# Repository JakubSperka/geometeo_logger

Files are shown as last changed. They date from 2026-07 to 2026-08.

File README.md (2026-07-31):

# GeoMeteo Logger

**Prenosný záznamník atmosférických parametrov pre geodetické merania**

> [!NOTE]
> Dokumentácia opisuje aktuálnu vývojovú vetvu **v0.9.0**.  
> Posledný overený stabilný build základnej funkcionality je **v0.9.0**.

GeoMeteo Logger je prenosné zariadenie určené na meranie a záznam:

- teploty vzduchu,
- relatívnej vlhkosti,
- atmosférického tlaku,
- napätia a odhadovaného stavu batérie.

Merania sa ukladajú na SD kartu vo formáte CSV. Zariadenie podporuje automatické aj manuálne záznamy, meracie relácie, živé grafy, obnovu po reštarte, kalibráciu, úsporný režim displeja a bezdrôtový export ukončených relácií cez Wi‑Fi.

> [!NOTE]
> **PLACEHOLDER – FOTO ZARIADENIA**  
> Doplňte fotografiu kompletného zariadenia.  
> Odporúčaný súbor: `docs/images/geometeo-logger-overview.jpg`

---

## Obsah

1. [Hlavné funkcie](#hlavné-funkcie)
2. [Hardvér](#hardvér)
3. [Prvé spustenie](#prvé-spustenie)
4. [Hlavná obrazovka](#hlavná-obrazovka)
5. [Meracie relácie](#meracie-relácie)
6. [Automatické a manuálne záznamy](#automatické-a-manuálne-záznamy)
7. [Grafy](#grafy)
8. [Archív relácií](#archív-relácií)
9. [Kalibrácia](#kalibrácia)
10. [Nastavenia](#nastavenia)
11. [Úspora energie](#úspora-energie)
12. [Wi‑Fi export](#wi-fi-export)
13. [CSV súbory](#csv-súbory)
14. [Odporúčaný postup merania](#odporúčaný-postup-merania)
15. [Stavové a chybové hlásenia](#stavové-a-chybové-hlásenia)
16. [Obnova relácie po reštarte](#obnova-relácie-po-reštarte)
17. [Údržba](#údržba)
18. [Riešenie problémov](#riešenie-problémov)
19. [Štruktúra repozitára](#štruktúra-repozitára)
20. [Licencia](#licencia)

---

## Hlavné funkcie

GeoMeteo Logger poskytuje:

- živé zobrazenie teploty, vlhkosti a tlaku,
- automatický zápis v intervale 1, 5, 10, 30 alebo 60 sekúnd,
- manuálny záznam priradený ku konkrétnemu meranému bodu,
- meraciu reláciu s pevným stanoviskom,
- ukladanie údajov na SD kartu,
- oddelený CSV súbor pre každú reláciu,
- živé grafy posledných 120 záznamov alebo celej relácie,
- archív ukončených relácií,
- obnovenie nedokončenej relácie po reštarte,
- lineárnu kalibráciu každého senzora,
- uloženie surových aj korigovaných hodnôt,
- nastaviteľný jas displeja,
- automatické stlmenie a vypnutie podsvietenia,
- voľbu farebnej schémy používateľského rozhrania,
- export CSV cez vlastnú Wi‑Fi sieť zariadenia,
- validáciu meraných hodnôt a opakovaný pokus o zápis na SD kartu.

---

## Hardvér

### Hlavné komponenty

| Komponent | Použitie |
|---|---|
| LaskaKit ESPD‑35 v3.2 | hlavná doska s ESP32‑S3, TFT displejom a dotykom |
| TFT ILI9488, 480 × 320 px | používateľské rozhranie |
| FT5436/FT6236 | dotyková vrstva |
| SHT40 | teplota a relatívna vlhkosť |
| BMP280 | atmosférický tlak |
| DS3231 | dátum a čas |
| SD karta | ukladanie meracích relácií |
| Li‑Po batéria | prenosné napájanie |

> [!NOTE]
> **PLACEHOLDER – SCHÉMA HARDVÉRU**  
> Doplňte blokovú schému zapojenia zariadenia.  
> Odporúčaný súbor: `docs/images/hardware-block-diagram.png`

### Použité zbernice a piny

#### Interná I²C zbernica

| Signál | GPIO |
|---|---:|
| SDA | 42 |
| SCL | 2 |

Interná zbernica je použitá najmä pre dotykový ovládač. Interné senzory dosky sa vo firmvéri GeoMeteo Logger nepoužívajú.

#### Externá I²C zbernica

| Signál | GPIO |
|---|---:|
| SDA | 5 |
| SCL | 6 |

| Zariadenie | I²C adresa |
|---|---:|
| SHT40 | `0x44` |
| DS3231 | `0x68` |
| BMP280 | `0x77` |

#### SD karta

| Signál | GPIO |
|---|---:|
| SCK | 14 |
| MISO | 21 |
| MOSI | 38 |
| CS | 17 |

#### Batéria

Meranie napätia batérie je pripojené na `GPIO9`.

---

## Prvé spustenie

1. Vložte SD kartu naformátovanú na **FAT32**.
2. Pripojte externý meteorologický modul a RTC.
3. Zapnite zariadenie.
4. Počkajte na dokončenie inicializácie.
5. Skontrolujte stavové indikátory na hlavnej obrazovke.
6. Nastavte správny dátum a čas.
7. Nastavte požadovaný interval automatického záznamu.
8. Pred prvým ostrým meraním vytvorte krátku skúšobnú reláciu.

Po úspešnom štarte sa zobrazí názov projektu a verzia firmvéru:

```text
GEOMETEO LOGGER
vX.Y.Z
```

> [!NOTE]
> **PLACEHOLDER – FOTO ÚVODNEJ OBRAZOVKY**  
> Doplňte fotografiu alebo snímku úvodnej obrazovky.  
> Odporúčaný súbor: `docs/images/startup-screen.jpg`

---

## Hlavná obrazovka

Hlavná obrazovka zobrazuje:

- aktuálny dátum a čas,
- stav batérie,
- teplotu,
- relatívnu vlhkosť,
- atmosférický tlak,
- stanovisko,
- aktuálny meraný bod,
- počet manuálnych záznamov,
- stav senzorov, SD karty, relácie a záznamu,
- tlačidlo na spustenie alebo ukončenie relácie,
- tlačidlo na manuálne uloženie merania,
- skratky do archívu, grafov, Wi‑Fi exportu a nastavení.

> [!NOTE]
> **PLACEHOLDER – HLAVNÁ OBRAZOVKA**  
> Doplňte snímku hlavnej obrazovky s popisom jednotlivých prvkov.  
> Odporúčaný súbor: `docs/images/main-screen-annotated.png`

### Stavové indikátory

Farba bodu vyjadruje stav:

| Farba | Význam |
|---|---|
| zelená | funkcia je pripravená alebo zápis prebehol správne |
| oranžová | upozornenie alebo prechodný stav |
| červená | chyba alebo nedostupná funkcia |
| sivá | funkcia nie je aktívna |

Sledované stavy:

- `SENZOR`
- `SD`
- `RELACIA`
- `ZAZNAM`

---

## Meracie relácie

Každé meranie sa organizuje do samostatnej relácie.

Relácia obsahuje:

- identifikátor relácie,
- stanovisko,
- čas začiatku a konca,
- automatické záznamy,
- manuálne záznamy,
- merané body,
- kalibračné nastavenia použité pri meraní.

### Spustenie relácie

1. Stlačte **SPUSTIT RELACIU**.
2. Zadajte názov alebo číslo stanoviska.
3. Potvrďte zadanie.
4. Zariadenie vytvorí nový CSV súbor.
5. Automatický záznam začne podľa nastaveného intervalu.

Stanovisko je počas relácie uzamknuté.

### Ukončenie relácie

1. Stlačte **UKONCIT RELACIU**.
2. Potvrďte ukončenie.
3. Do CSV sa uloží systémový záznam `SESSION_END`.
4. Súbor zostane dostupný v archíve a cez Wi‑Fi export.

> [!WARNING]
> Pred vypnutím zariadenia odporúčame reláciu vždy korektne ukončiť. Pri neočakávanom vypnutí je však možné reláciu obnoviť.

---

## Automatické a manuálne záznamy

### Automatický záznam

Automatické záznamy sa ukladajú počas aktívnej relácie v nastavenom intervale.

Dostupné intervaly:

- 1 sekunda,
- 5 sekúnd,
- 10 sekúnd,
- 30 sekúnd,
- 60 sekúnd.

Automatický záznam má typ:

```text
AUTO
```

Meraný bod zostáva pri automatickom zázname prázdny.

### Manuálny záznam

Manuálny záznam sa používa na priradenie atmosférických podmienok ku konkrétnemu cieľovému bodu.

Postup:

1. Spustite reláciu.
2. Zadajte meraný bod.
3. Stlačte **ULOZIT MERANIE**.
4. Po úspešnom zápise sa zvýši počítadlo `MANUAL`.
5. Pole meraného bodu sa vymaže a je pripravené na ďalšie zadanie.

Manuálny záznam má typ:

```text
MANUAL
```

Maximálna dĺžka identifikátora stanoviska alebo bodu je 16 znakov.

Podporované sú:

- písmená `A–Z`,
- číslice `0–9`,
- `_`
- `.`
- `,`
- `-`

---

## Grafy

Grafické menu je dostupné počas aktívnej relácie aj z archívu ukončených relácií.

Zobrazované veličiny:

- teplota,
- relatívna vlhkosť,
- atmosférický tlak.

### Rozsah grafu

#### Posledných 120 záznamov

Voľba `120` zobrazí posledných 120 automatických záznamov.

Približný časový rozsah:

| Interval zápisu | Rozsah 120 záznamov |
|---:|---:|
| 1 s | 2 minúty |
| 5 s | 10 minút |
| 10 s | 20 minút |
| 30 s | 1 hodina |
| 60 s | 2 hodiny |

#### Všetky záznamy

Voľba `VSETKY` spracuje celú reláciu. Na displeji sa zobrazí najviac 240 grafických bodov. Pri väčšom počte záznamov sa údaje agregujú, ale minimum, maximum a priemer sa počítajú zo všetkých dostupných záznamov.

### Živé grafy

Počas aktívnej relácie sa graf posledných 120 záznamov aktualizuje po každom úspešnom automatickom zápise.

> [!NOTE]
> **PLACEHOLDER – OBRAZOVKA GRAFOV**  
> Doplňte snímku grafu teploty, vlhkosti a tlaku.  
> Odporúčaný súbor: `docs/images/graphs-screen.png`

---

## Archív relácií

Archív zobrazuje korektne ukončené relácie uložené na SD karte.

Relácie sú:

- zoradené od najnovšej,
- stránkované,
- označené stanoviskom, dátumom, časom a veľkosťou súboru.

Detail relácie obsahuje:

- stanovisko,
- začiatok a koniec,
- trvanie,
- počet automatických záznamov,
- počet manuálnych záznamov,
- minimum, maximum a priemer meraných veličín,
- prístup ku grafom relácie.

Do archívu sa zaraďujú relácie ukončené záznamom:

- `SESSION_END`
- `SESSION_END_RECOVERY`
- `SESSION_ABANDONED`

Aktívna alebo nedokončená relácia sa v archíve nezobrazuje.

> [!NOTE]
> **PLACEHOLDER – ARCHÍV RELÁCIÍ**  
> Doplňte snímku zoznamu relácií a detailu jednej relácie.  
> Odporúčané súbory:  
> `docs/images/archive-list.png`  
> `docs/images/archive-detail.png`

---

## Kalibrácia

Kalibrácia slúži na korekciu rozdielu medzi GeoMeteo Loggerom a referenčným meradlom.

Pre každú veličinu sa používa lineárna korekcia:

```text
korigovaná hodnota = a × meraná hodnota + b
```

Kde:

- `a` je mierkový koeficient,
- `b` je offset.

Kalibrovať možno samostatne:

- teplotu,
- relatívnu vlhkosť,
- atmosférický tlak.

### Neutrálne nastavenie

```text
a = 1.000000
b = 0.000
```

Pri neutrálnom nastavení sa meraná hodnota nemení.

### Povolené rozsahy

| Parameter | Minimum | Maximum |
|---|---:|---:|
| mierkový koeficient `a` | 0,5 | 1,5 |
| teplotný offset `b` | −20 °C | +20 °C |
| vlhkostný offset `b` | −50 % | +50 % |
| tlakový offset `b` | −150 hPa | +150 hPa |

### Uloženie kalibrácie

Kalibračné koeficienty sa ukladajú do internej pamäte ESP32 a zostávajú zachované po reštarte alebo vypnutí zariadenia.

Kalibráciu nemožno meniť počas aktívnej relácie.

> [!IMPORTANT]
> Zmena kalibračných koeficientov je používateľská konfigurácia. Nemení číslo verzie firmvéru.

### Odporúčané získanie koeficientov

1. Umiestnite GeoMeteo Logger a referenčné meradlo vedľa seba.
2. Nechajte oba prístroje ustáliť.
3. Vykonajte viacero súčasných odčítaní.
4. Použite údaje na výpočet lineárnej korekcie.
5. Koeficienty zadajte v kalibračnom menu.
6. Vykonajte kontrolné meranie.

> [!NOTE]
> **PLACEHOLDER – KALIBRAČNÉ MENU**  
> Doplňte snímku obrazovky kalibrácie.  
> Odporúčaný súbor: `docs/images/calibration-screen.png`

---

## Nastavenia

V nastaveniach možno upraviť:

- dátum a čas RTC,
- interval automatického záznamu,
- jas displeja,
- kalibráciu,
- úsporu energie,
- farebnú schému používateľského rozhrania.

### Dátum a čas

Dátum a čas sa nastavujú v samostatnom editore. Zmena ostatných nastavení nemení RTC.

### Jas displeja

Jas možno nastaviť v rozsahu približne 10 až 100 %.

### Farebná schéma

Dostupné akcentové farby:

- oranžová,
- modrá,
- zelená,
- červená,
- fialová.

Výber sa uloží do internej pamäte a zostane zachovaný po reštarte.

Farebná schéma ovplyvňuje najmä:

- panely meraných hodnôt,
- aktívne tlačidlá,
- ikony,
- rámčeky,
- posuvník jasu,
- grafické akcenty,
- webovú stránku Wi‑Fi exportu.

Stavové farby upozornení zostávajú nezávislé od zvolenej schémy.

> [!NOTE]
> **PLACEHOLDER – NASTAVENIA A FARBY**  
> Doplňte snímku hlavného nastavenia a výberu farebnej schémy.  
> Odporúčané súbory:  
> `docs/images/settings-screen.png`  
> `docs/images/accent-theme-screen.png`

---

## Úspora energie

Úsporný režim ovplyvňuje iba podsvietenie displeja. Meranie a zápis na SD kartu pokračujú bez prerušenia.

Dostupný čas nečinnosti pred stlmením:

- 30 sekúnd,
- 1 minúta,
- 2 minúty,
- 5 minút.

Po uplynutí nastaveného času:

1. displej sa stlmí približne na 5 %,
2. po ďalších 30 sekundách sa podsvietenie vypne,
3. prvý dotyk displej iba prebudí,
4. až ďalší dotyk vykoná požadovanú akciu.

Predvolené nastavenie:

```text
úspora energie: zapnutá
stlmenie: po 1 minúte
vypnutie: o ďalších 30 sekúnd
```

Počas Wi‑Fi exportu zostáva displej aktívny.

---

## Wi‑Fi export

GeoMeteo Logger umožňuje stiahnuť ukončené CSV relácie bez vyberania SD karty.

Zariadenie vytvorí vlastnú Wi‑Fi sieť. Router ani internet nie sú potrebné.

### Spustenie exportu

1. Ukončite aktívnu meraciu reláciu.
2. Otvorte Wi‑Fi menu.
3. Stlačte **SPUSTIT WI-FI**.
4. V počítači alebo telefóne vyhľadajte sieť:

```text
GeoMeteo-XXXX
```

5. Pripojte sa pomocou hesla:

```text
geometeo
```

6. V prehliadači otvorte:

```text
http://192.168.4.1
```

7. Vyberte reláciu a stlačte **STIAHNUT CSV**.

### Dôležité vlastnosti

- exportujú sa iba ukončené relácie,
- aktívnu reláciu nemožno exportovať,
- Wi‑Fi sa po piatich minútach bez aktivity automaticky vypne,
- odchod z Wi‑Fi menu export ukončí,
- CSV sa prenáša priamo zo SD karty,
- pripojenie nemá prístup na internet.

> [!NOTE]
> Telefón alebo počítač môže oznámiť, že Wi‑Fi sieť nemá internet. Zostaňte k nej pripojení a ručne otvorte adresu `192.168.4.1`.

> [!NOTE]
> **PLACEHOLDER – WI‑FI EXPORT**  
> Doplňte fotografiu Wi‑Fi menu a snímku webovej stránky.  
> Odporúčané súbory:  
> `docs/images/wifi-export-device.png`  
> `docs/images/wifi-export-browser.png`

---

## CSV súbory

Každá relácia sa ukladá do samostatného súboru v priečinku:

```text
/sessions
```

### Stĺpce CSV

| Stĺpec | Význam |
|---|---|
| `session_id` | identifikátor relácie |
| `timestamp` | dátum a čas záznamu |
| `record_type` | typ záznamu |
| `station` | stanovisko |
| `target_point` | meraný bod |
| `temperature_c` | korigovaná teplota |
| `humidity_pct` | korigovaná relatívna vlhkosť |
| `pressure_hpa` | korigovaný atmosférický tlak |
| `battery_voltage_v` | napätie batérie |
| `battery_percent` | odhad stavu batérie |
| `temperature_raw_c` | pôvodná hodnota teploty |
| `humidity_raw_pct` | pôvodná hodnota vlhkosti |
| `pressure_raw_hpa` | pôvodná hodnota tlaku |
| `calibration_enabled` | stav kalibrácie |
| `temperature_scale` | koeficient `a` pre teplotu |
| `temperature_offset_c` | koeficient `b` pre teplotu |
| `humidity_scale` | koeficient `a` pre vlhkosť |
| `humidity_offset_pct` | koeficient `b` pre vlhkosť |
| `pressure_scale` | koeficient `a` pre tlak |
| `pressure_offset_hpa` | koeficient `b` pre tlak |

### Typy záznamov

| Typ | Význam |
|---|---|
| `SESSION_START` | začiatok relácie |
| `AUTO` | automatický merací záznam |
| `MANUAL` | manuálny záznam ku konkrétnemu bodu |
| `SESSION_RESUME` | pokračovanie obnovenej relácie |
| `SESSION_END` | korektné ukončenie relácie |
| `SESSION_END_RECOVERY` | ukončenie obnovenej relácie |
| `SESSION_ABANDONED` | opustenie nedokončenej relácie |

### Ukážka

```csv
session_id,timestamp,record_type,station,target_point,temperature_c,humidity_pct,pressure_hpa,battery_voltage_v,battery_percent,temperature_raw_c,humidity_raw_pct,pressure_raw_hpa,calibration_enabled,temperature_scale,temperature_offset_c,humidity_scale,humidity_offset_pct,pressure_scale,pressure_offset_hpa
20260727_083200,2026-07-27 08:32:00,SESSION_START,ST_01,,,,4.08,87,,,,0,1.000000,0.000,1.000000,0.000,1.000000,0.000
20260727_083200,2026-07-27 08:32:05,AUTO,ST_01,,24.53,46.10,999.35,4.08,87,24.53,46.10,999.35,0,1.000000,0.000,1.000000,0.000,1.000000,0.000
20260727_083200,2026-07-27 08:33:12,MANUAL,ST_01,BOD_101,24.55,46.20,999.34,4.07,86,24.55,46.20,999.34,0,1.000000,0.000,1.000000,0.000,1.000000,0.000
```

> [!NOTE]
> Uvedené hodnoty sú iba ilustračné.

---

## Odporúčaný postup merania

### Pred meraním

1. Skontrolujte nabitie batérie.
2. Skontrolujte vloženie SD karty.
3. Overte dátum a čas.
4. Skontrolujte stav senzorov.
5. Nechajte zariadenie ustáliť v prostredí merania.
6. Až potom spustite reláciu.

### Odporúčaná doba ustálenia

Firmvér neobsahuje povinnú čakaciu dobu. Používateľ môže reláciu spustiť okamžite.

Pre spoľahlivejšie výsledky sa odporúča:

| Situácia | Odporúčaná doba |
|---|---:|
| bežné spustenie | približne 60 sekúnd |
| výrazná zmena prostredia | 5 až 10 minút |
| kalibračné porovnanie | 10 až 15 minút |

### Umiestnenie senzora

Senzor umiestnite:

- mimo priameho slnečného žiarenia,
- mimo tepla ruky používateľa,
- mimo výduchu teplého vzduchu,
- s dostatočným prúdením vzduchu,
- čo najďalej od elektroniky a displeja,
- v ochrannom, ale vetranom kryte.

> [!NOTE]
> **PLACEHOLDER – UMIESTNENIE SENZORA**  
> Doplňte fotografiu odporúčaného umiestnenia externého senzora v kryte.  
> Odporúčaný súbor: `docs/images/sensor-placement.jpg`

---

## Stavové a chybové hlásenia

Zariadenie kontroluje:

- komunikáciu so SHT40,
- komunikáciu s BMP280,
- platnosť RTC,
- dostupnosť SD karty,
- úspešnosť zápisu,
- platnosť meraných rozsahov,
- stav batérie.

Príklady hlásení:

```text
CHYBA CITANIA SHT40
CHYBA CITANIA BMP280
NEPLATNY DATUM ALEBO CAS RTC
TEPLOTA MIMO PLATNEHO ROZSAHU
VLHKOST MIMO PLATNEHO ROZSAHU
TLAK MIMO PLATNEHO ROZSAHU
CHYBA ZAPISU NA SD
BATERIA KRITICKA
```

Neplatné meranie sa neuloží ako `AUTO` ani `MANUAL`.

### Platné rozsahy meraní

| Veličina | Minimum | Maximum |
|---|---:|---:|
| teplota | −40 °C | 85 °C |
| relatívna vlhkosť | 0 % | 100 % |
| tlak | 300 hPa | 1100 hPa |
| rok RTC | 2020 | 2099 |

### Batéria

| Stav | Indikácia |
|---|---|
| viac ako 25 % | zelená |
| 11 až 25 % | oranžová |
| 0 až 10 % | červená |

Pri kritickej úrovni zariadenie odporučí ukončiť reláciu, ale nevypne ju automaticky.

---

## Obnova relácie po reštarte

Po neočakávanom vypnutí alebo reštarte zariadenie rozpozná nedokončenú reláciu.

Používateľ môže zvoliť:

### Pokračovať

- obnoví stanovisko,
- obnoví CSV súbor,
- obnoví počet manuálnych záznamov,
- zapíše `SESSION_RESUME`.

### Ukončiť

- uzavrie pôvodnú reláciu,
- zapíše `SESSION_END_RECOVERY`.

### Nová relácia

- označí pôvodnú reláciu ako `SESSION_ABANDONED`,
- vymaže uložený aktívny stav,
- umožní založiť novú reláciu.

> [!NOTE]
> **PLACEHOLDER – OBNOVA RELÁCIE**  
> Doplňte snímku obrazovky obnovy po reštarte.  
> Odporúčaný súbor: `docs/images/session-recovery.png`

---

## Údržba

### SD karta

- používajte kartu naformátovanú na FAT32,
- kartu nevyberajte počas zápisu,
- pred vybratím ukončite reláciu a vypnite zariadenie,
- pravidelne zálohujte CSV súbory,
- pri opakovaných chybách zápisu kartu preformátujte alebo vymeňte.

### Senzory

- chráňte ich pred kondenzáciou a priamym dažďom,
- nevystavujte ich zbytočne prachu,
- neumiestňujte ich do uzavretého nevetraného priestoru,
- pred kalibráciou zabezpečte rovnaké podmienky pre oba prístroje.

### Batéria

- zariadenie nabíjajte vhodným USB zdrojom,
- nenechávajte batériu dlhodobo úplne vybitú,
- pri dlhšom skladovaní zariadenie pravidelne skontrolujte.

---

## Riešenie problémov

### Zariadenie nevidí SD kartu

1. Vypnite zariadenie.
2. Skontrolujte vloženie karty.
3. Overte formát FAT32.
4. Skúste inú SD kartu.
5. Skontrolujte stav `SD` po opätovnom zapnutí.

### Meranie sa neukladá

Skontrolujte:

- či je aktívna relácia,
- či je zadané stanovisko,
- pri manuálnom zázname aj meraný bod,
- stav SD karty,
- platnosť hodnôt senzorov.

Počítadlo manuálnych záznamov sa zvýši iba po potvrdenom zápise.

### Zobrazované hodnoty sa líšia od referenčného meradla

1. Nechajte oba prístroje ustáliť.
2. Skontrolujte ich umiestnenie.
3. Pri tlaku overte, že oba prístroje zobrazujú rovnaký typ tlaku.
4. Vykonajte viacero porovnávacích meraní.
5. Vypočítajte a nastavte kalibračné koeficienty.

### Wi‑Fi stránka sa neotvorí

1. Overte, že je Wi‑Fi export spustený.
2. Skontrolujte pripojenie k sieti `GeoMeteo-XXXX`.
3. Zostaňte pripojení aj bez internetu.
4. Otvorte priamo `http://192.168.4.1`.
5. Skontrolujte, či sa Wi‑Fi po časovom limite nevypnula.

### CSV súbor sa nedá stiahnuť

- relácia musí byť ukončená,
- SD karta musí byť dostupná,
- Wi‑Fi musí zostať aktívna počas celého prenosu,
- pri veľkom súbore počkajte na dokončenie prenosu.

### Displej nereaguje na prvý dotyk

Pri stlmenom alebo vypnutom displeji je to očakávané správanie. Prvý dotyk iba prebudí podsvietenie. Druhý dotyk vykoná požadovanú akciu.

---

## Štruktúra repozitára

Odporúčaná štruktúra:

```text
GeoMeteo-Logger/
├── README.md
├── LICENSE
├── firmware/
│   ├── geometeo_logger.ino
│   ├── FT6236.h
│   └── FT6236.cpp
├── docs/
│   ├── user-guide.md
│   ├── hardware.md
│   ├── csv-format.md
│   └── images/
│       ├── geometeo-logger-overview.jpg
│       ├── hardware-block-diagram.png
│       ├── main-screen-annotated.png
│       ├── graphs-screen.png
│       ├── archive-list.png
│       ├── archive-detail.png
│       ├── calibration-screen.png
│       ├── settings-screen.png
│       ├── accent-theme-screen.png
│       ├── wifi-export-device.png
│       ├── wifi-export-browser.png
│       ├── sensor-placement.jpg
│       └── session-recovery.png
└── examples/
    └── sample-session.csv
```

---

## Vývojové prostredie

Projekt bol vyvíjaný a testovaný s:

- Arduino IDE 2.3.10,
- balíkom ESP32 3.3.11,
- doskou LaskaKit ESPD‑35 v3.2.

Použité knižnice:

```cpp
#include <Arduino.h>
#include <Wire.h>
#include <SPI.h>
#include <FS.h>
#include <SD.h>
#include <TFT_eSPI.h>
#include "FT6236.h"
#include <Adafruit_SHT4x.h>
#include <Adafruit_BMP280.h>
#include <RTClib.h>
#include <Preferences.h>
#include <WiFi.h>
#include <WebServer.h>
```

Pre TFT_eSPI sa používa konfigurácia displeja určená pre ESPD‑35 v3:

```text
Setup303_ILI9488_ESPD-3_5_v3.h
```

---

## Verzionovanie

Projekt používa verzie vo formáte:

```text
MAJOR.MINOR.PATCH
```

Príklad:

```text
v0.8.0
```

- `MAJOR` – zásadná zmena alebo stabilné verejné vydanie,
- `MINOR` – nová funkcia,
- `PATCH` – oprava alebo menšia úprava.

Zmena používateľských nastavení, napríklad kalibračných koeficientov, jasu, intervalu alebo farebnej schémy, nemení verziu firmvéru.

---

## Licencia

```text
MIT License
```

Výber závisí od požadovaných podmienok ďalšieho používania a úprav.

---

## Autor a kontakt

```text
Autor: Jakub Špekra
Pracovisko: Karedra globálnej geodézie a geoinformatiky, Stavebná Fakulta STU v Bratislava
E-mail: jakub.sperka@stuba.sk
Repozitár: geometeo_logger
```

---

## Stav projektu

GeoMeteo Logger poskytuje kompletný pracovný tok pre terénny záznam atmosférických parametrov:

```text
spustenie
→ kontrola zariadení
→ založenie relácie
→ automatické a manuálne meranie
→ grafická kontrola
→ ukončenie relácie
→ archív
→ export CSV cez Wi‑Fi
→ spracovanie údajov v počítači
```

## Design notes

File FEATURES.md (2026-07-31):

# GeoMeteo Logger – prehľad funkcionalít

Tento dokument sumarizuje funkcionalitu zariadenia **GeoMeteo Logger** implementovanú vo firmvéri do verzie **v0.9.0**.

> [!NOTE]
> Verzia **v0.7.6** bola označená ako stabilný referenčný build.  
> Verzia **v0.9.0** obsahuje všetky neskoršie rozšírenia vrátane farebných schém a ochrany úložiska a je určená na overenie pred označením za nový stable release.

---

## 1. Merané veličiny

Zariadenie meria a zobrazuje:

- teplotu vzduchu zo senzora SHT40,
- relatívnu vlhkosť zo senzora SHT40,
- absolútny atmosférický tlak zo senzora BMP280,
- napätie Li‑Po batérie,
- odhad percentuálneho stavu batérie,
- dátum a čas z RTC DS3231.

Interné meteorologické senzory hlavnej dosky sa nepoužívajú. Firmvér pracuje s externým meteorologickým modulom na samostatnej I²C zbernici.

### Frekvencia čítania senzorov

Atmosférické hodnoty sa interne obnovujú približne každú sekundu bez ohľadu na nastavený interval zápisu do CSV.

### Kontrola platnosti meraní

Pred uložením sa kontrolujú rozsahy:

| Veličina | Minimum | Maximum |
|---|---:|---:|
| teplota | −40 °C | 85 °C |
| relatívna vlhkosť | 0 % | 100 % |
| tlak | 300 hPa | 1100 hPa |
| rok RTC | 2020 | 2099 |

Pri neplatnej hodnote sa automatický ani manuálny merací záznam neuloží. Systémové udalosti relácie sa môžu uložiť aj bez platných atmosferických hodnôt.

---

## 2. Hlavná obrazovka

Hlavná obrazovka v portrétnej orientácii zobrazuje:

- dátum a čas,
- percento a napätie batérie,
- teplotu,
- relatívnu vlhkosť,
- tlak,
- stanovisko,
- aktuálny meraný bod,
- počet manuálnych záznamov vo formáte `MANUAL: n`,
- stavový riadok s aktuálnou informáciou alebo chybou,
- stavové indikátory zariadenia,
- tlačidlo na spustenie alebo ukončenie relácie,
- tlačidlo manuálneho uloženia,
- skratky do archívu, grafov, Wi‑Fi exportu a nastavení.

Merané hodnoty používajú jemne zosilnený čierny font na farebnom pozadí.

### Stavové indikátory

Indikátory používajú celé názvy:

- `SENZOR`
- `SD`
- `RELACIA`
- `ZAZNAM`

Ich farby nepodliehajú používateľskej farebnej téme:

| Farba | Význam |
|---|---|
| zelená | pripravené alebo úspešné |
| oranžová | upozornenie, čakanie alebo neaktívny stav |
| červená | chyba |

---

## 3. Meracie relácie

Každé meranie sa organizuje do samostatnej relácie.

### Spustenie relácie

Jedno kontextové tlačidlo slúži na spustenie aj ukončenie relácie:

```text
SPUSTIT RELACIU
UKONCIT RELACIU
```

Pri spustení používateľ zadá stanovisko. Stanovisko zostáva počas celej relácie nemenné.

### Identifikátory

Stanovisko a meraný bod môžu mať najviac 16 znakov.

Podporované znaky:

- `A–Z`
- `0–9`
- `_`
- `.`
- `,`
- `-`

CSV zápis správne uzatvára textové polia do úvodzoviek, ak obsahujú čiarku alebo úvodzovku.

### Ukončenie relácie

Ukončenie sa vykonáva cez potvrdzovaciu obrazovku. Pri úspešnom ukončení sa zapíše systémová udalosť `SESSION_END`.

---

## 4. Automatický záznam

Počas aktívnej relácie sa údaje automaticky zapisujú do CSV.

Dostupné intervaly:

- 1 sekunda,
- 5 sekúnd,
- 10 sekúnd,
- 30 sekúnd,
- 60 sekúnd.

Predvolený interval je 5 sekúnd.

Automatický záznam má typ:

```text
AUTO
```

Pole meraného bodu zostáva pri automatickom zázname prázdne.

---

## 5. Manuálny záznam

Manuálny záznam umožňuje priradiť aktuálne atmosferické podmienky ku konkrétnemu meranému bodu.

Pracovný postup:

1. spustenie relácie,
2. zadanie meraného bodu,
3. uloženie merania,
4. potvrdenie úspešného zápisu,
5. zvýšenie počítadla `MANUAL`,
6. automatické vymazanie poľa meraného bodu.

Manuálny záznam má typ:

```text
MANUAL
```

Počítadlo sa zvýši iba po potvrdenom zápise na SD kartu.

---

## 6. Softvérová klávesnica

Zariadenie obsahuje dotykovú alfanumerickú klávesnicu.

Podporuje:

- číselný režim,
- abecedný režim,
- prepínanie režimov,
- mazanie posledného znaku,
- vymazanie celého vstupu,
- potvrdenie a zrušenie zadávania,
- samostatný numerický editor kalibračných koeficientov.

---

## 7. Ukladanie na SD kartu

Každá relácia má vlastný CSV súbor v priečinku:

```text
/sessions
```

### Bezpečný zápis

Pri každom zázname firmvér:

1. otvorí súbor v režime append,
2. zapíše celý CSV riadok,
3. vykoná `flush()`,
4. skontroluje chybu zápisu,
5. zatvorí súbor.

Pri chybe zápisu:

- označí SD kartu ako chybnú,
- ukončí aktuálne spojenie,
- znovu inicializuje SPI a SD kartu,
- zopakuje zápis,
- vykoná najviac dva pokusy.

Opakovaná inicializácia SD karty sa vykonáva najskôr po približne piatich sekundách.

### CSV obsah

CSV uchováva:

- identifikátor relácie,
- čas záznamu,
- typ záznamu,
- stanovisko,
- meraný bod,
- korigované hodnoty,
- napätie a percento batérie,
- surové hodnoty senzorov,
- stav kalibrácie,
- všetky kalibračné koeficienty.

### Systémové typy záznamov

Firmvér používa:

- `SESSION_START`
- `AUTO`
- `MANUAL`
- `SESSION_RESUME`
- `SESSION_END`
- `SESSION_END_RECOVERY`
- `SESSION_ABANDONED`
- `FILE_CONTINUE`
- `FILE_RESUME`

---

## 8. Ochrana FAT32 a kontrola voľného miesta

Od verzie v0.9.0 firmvér aktívne kontroluje veľkosť súborov aj kapacitu SD karty.

### Automatické delenie súborov

FAT32 povoľuje maximálnu veľkosť jedného súboru 4 GiB − 1 bajt. Firmvér reláciu preventívne rozdelí pri približne:

```text
3800 MiB
```

Pokračovacie súbory používajú názvy:

```text
session.csv
session_part02.csv
session_part03.csv
```

Pri prechode medzi časťami sa zapíšu udalosti:

```text
FILE_CONTINUE
FILE_RESUME
```

Všetky časti majú rovnaké `session_id`.

Podporovaných je najviac 32 častí jednej relácie.

### Testovací režim rotácie

Na overenie bez vytvárania veľkého súboru možno dočasne nastaviť:

```cpp
constexpr bool STORAGE_ROTATION_TEST_MODE = true;
```

V testovacom režime sa súbor rozdelí približne pri 64 KiB. V produkčnej verzii musí zostať hodnota `false`.

### Kontrola voľného priestoru

Firmvér rozlišuje:

| Hranica | Správanie |
|---:|---|
| 32 MiB | upozornenie na nízky voľný priestor |
| 4 MiB | zastavenie bežných meracích zápisov |
| 64 KiB | núdzová rezerva pre korektné ukončenie relácie |

Kapacita SD sa pravidelne kontroluje približne každých päť sekúnd.

Grafy, archív a Wi‑Fi export dokážu pracovať s viacdielnou reláciou ako s jedným logickým meraním.

---

## 9. Obnova relácie po reštarte

Stav aktívnej relácie sa priebežne ukladá do internej pamäte ESP32.

Uchováva sa:

- identifikátor relácie,
- stanovisko,
- meraný bod,
- aktuálny CSV súbor,
- základná cesta relácie,
- číslo aktuálnej časti súboru,
- počet manuálnych záznamov.

Po neočakávanom reštarte možno zvoliť:

### Pokračovať

- obnoví sa pôvodná relácia,
- pokračuje sa v existujúcom súbore,
- zapíše sa `SESSION_RESUME`.

### Ukončiť

- pôvodná relácia sa uzavrie,
- zapíše sa `SESSION_END_RECOVERY`.

### Nová relácia

- pôvodná relácia sa označí ako opustená,
- zapíše sa `SESSION_ABANDONED`,
- používateľ môže založiť novú reláciu.

---

## 10. Kalibrácia

Pre teplotu, vlhkosť a tlak možno nastaviť samostatnú lineárnu korekciu:

```text
korigovaná hodnota = a × meraná hodnota + b
```

### Dostupné parametre

- mierkový koeficient `a`,
- offset `b`,
- globálne zapnutie alebo vypnutie kalibrácie.

### Rozsahy

| Parameter | Rozsah |
|---|---:|
| mierka `a` | 0,5 až 1,5 |
| teplotný offset | −20 až +20 °C |
| vlhkostný offset | −50 až +50 % |
| tlakový offset | −150 až +150 hPa |

### Vlastnosti

- kalibračné menu zobrazuje meranú aj korigovanú hodnotu,
- koeficienty sa ukladajú do `Preferences`,
- zostávajú zachované po reštarte,
- počas aktívnej relácie ich nemožno meniť,
- vypnutie kalibrácie koeficienty nevymaže,
- surové aj korigované hodnoty sa ukladajú do CSV.

Zmena koeficientov je používateľská konfigurácia a nemení verziu firmvéru.

---

## 11. Grafy

Grafy sú dostupné:

- počas aktívnej relácie,
- z detailu archivovanej relácie.

Zobrazujú:

- teplotu,
- vlhkosť,
- tlak.

### Rozsahy

#### `120`

Zobrazí posledných 120 automatických záznamov.

#### `VSETKY`

Spracuje celú reláciu. Na displeji sa vykreslí najviac 240 bodov. Pri väčšom počte záznamov sa údaje agregujú do intervalov.

### Štatistiky

Pre vybraný rozsah sa zobrazujú:

- minimum,
- priemer,
- maximum,
- čas prvého a posledného bodu.

### Živá aktualizácia

- režim `120` sa aktualizuje po každom úspešnom automatickom zápise,
- režim `VSETKY` sa pri menších reláciách aktualizuje priamo,
- pri veľkých reláciách sa znovu načíta najviac raz za 10 sekúnd,
- trvanie relácie a počítadlá sa obnovujú samostatne,
- používa sa čiastočné prekresľovanie na obmedzenie blikania obrazovky.

Viacdielne relácie sa pri grafoch spracujú v správnom poradí.

---

## 12. Archív relácií

Archív zobrazuje ukončené relácie uložené na SD karte.

### Vlastnosti

- najviac 96 najnovších relácií,
- päť relácií na jednu stránku,
- zoradenie od najnovšej,
- stránkovanie,
- manuálne obnovenie zoznamu,
- zobrazenie stanoviska, času a veľkosti,
- detail relácie,
- otvorenie grafov.

### Detail relácie

Zobrazuje:

- stanovisko,
- začiatok a koniec,
- trvanie,
- počet `AUTO` záznamov,
- počet `MANUAL` záznamov,
- minimum, priemer a maximum veličín,
- počet častí súboru,
- celkovú veľkosť všetkých častí.

Do archívu sa zaradia iba korektne ukončené alebo uzavreté relácie.

---

## 13. Wi‑Fi export

Zariadenie dokáže vytvoriť vlastnú Wi‑Fi sieť bez routera a internetu.

### Prístupový bod

```text
SSID: GeoMeteo-XXXX
Heslo: geometeo
Adresa: 192.168.4.1
Port: 80
```

Posledná časť SSID sa odvodí od konkrétneho ESP32.

### Funkcionalita webovej stránky

- zoznam ukončených relácií,
- dátum, čas a veľkosť súborov,
- stiahnutie CSV,
- samostatné stiahnutie jednotlivých častí viacdielnej relácie,
- farebné prispôsobenie podľa zvolenej témy zariadenia.

### Ochrany

- Wi‑Fi nemožno spustiť počas aktívnej relácie,
- exportujú sa iba ukončené relácie,
- pred stiahnutím sa súbor znovu overí,
- podporované sú najviac štyri súčasné klienty,
- Wi‑Fi sa vypne po piatich minútach bez aktivity,
- časový limit sa obnoví po dokončení prenosu,
- počas exportu zostáva displej aktívny,
- úsporný režim sa po ukončení exportu obnoví.

---

## 14. Batéria

Napätie batérie sa meria cez ADC s priemerovaním 16 vzoriek.

Používa sa nelineárna aproximačná krivka:

| Napätie | Stav |
|---:|---:|
| 3,20 V | 0 % |
| 3,50 V | 5 % |
| 3,60 V | 10 % |
| 3,70 V | 20 % |
| 3,75 V | 30 % |
| 3,79 V | 40 % |
| 3,83 V | 50 % |
| 3,87 V | 60 % |
| 3,92 V | 70 % |
| 4,00 V | 80 % |
| 4,10 V | 90 % |
| 4,20 V | 100 % |

Medzi bodmi sa používa lineárna interpolácia.

### Stavové hranice

| Stav batérie | Indikácia |
|---:|---|
| viac ako 25 % | zelená |
| 11 až 25 % | oranžová |
| 0 až 10 % | červená |

Pri kritickej batérii zariadenie používateľa upozorní, ale reláciu automaticky nevypne.

Detekcia aktívneho nabíjania nie je implementovaná.

---

## 15. Úspora energie

Firmvér umožňuje automaticky stlmiť a vypnúť podsvietenie displeja.

Dostupné časy nečinnosti:

- 30 sekúnd,
- 1 minúta,
- 2 minúty,
- 5 minút.

Správanie:

1. po nastavenom čase sa jas zníži na približne 5 %,
2. po ďalších 30 sekundách sa podsvietenie vypne,
3. prvý dotyk iba prebudí displej,
4. druhý dotyk vykoná akciu.

Počas vypnutého displeja pokračuje:

- čítanie senzorov,
- RTC,
- automatický zápis,
- kontrola SD,
- počítanie relácie,
- monitoring batérie.

Deep sleep sa nepoužíva.

---

## 16. Nastavenia

Používateľ môže nastaviť:

- dátum a čas RTC,
- interval automatického zápisu,
- jas displeja,
- kalibračné koeficienty,
- zapnutie úspory energie,
- čas stlmenia,
- farebnú schému.

Nastavenia sa ukladajú do `Preferences`.

Zmena jasu alebo intervalu nemení čas RTC.

---

## 17. Farebné schémy

Dostupné sú:

- oranžová,
- modrá,
- zelená,
- červená,
- fialová,
- sivá,
- žltá,
- limetková zelená,
- krémová,
- ružová.

Téma ovplyvňuje:

- panely meraných hodnôt,
- tlačidlá,
- ikony,
- aktívne voľby,
- rámčeky,
- posuvník jasu,
- grafické akcenty,
- Wi‑Fi webovú stránku.

Stavové indikátory používajú vždy pevnú zelenú, oranžovú a červenú.

---

## 18. RTC a čas

DS3231 poskytuje dátum a čas nezávislý od internetového pripojenia.

Firmvér obsahuje:

- editor dátumu,
- editor času,
- kontrolu platného roku,
- časové pečiatky pre všetky CSV udalosti,
- tvorbu identifikátora relácie z dátumu a času.

---

## 19. Verzia firmvéru

Názov a verzia sa zobrazujú:

- na úvodnej obrazovke,
- v nastaveniach,
- v Serial Monitore.

Verzia je definovaná centrálne:

```cpp
constexpr char APP_NAME[] = "GEOMETEO LOGGER";
constexpr char APP_VERSION[] = "v0.9.0";
```

---

## 20. Diagnostika a sériový výstup

Serial Monitor poskytuje informácie o:

- inicializácii zariadení,
- stave senzorov,
- SD karte,
- kapacite úložiska,
- vytvorení relácie,
- názve a časti súboru,
- manuálnych záznamoch,
- chybách zápisu,
- rotácii súborov,
- obnove relácie,
- Wi‑Fi exporte,
- úspore energie,
- kalibračných nastaveniach.

---

## 21. Zámerne neimplementované funkcie

Do aktuálneho firmvéru nie sú zahrnuté:

- povinná stabilizačná čakacia doba po zapnutí,
- automatické ukončenie relácie pri nízkej batérii,
- detekcia nabíjania,
- poznámky k reláciám a záznamom,
- mazanie alebo premenovanie relácií v zariadení,
- USB Mass Storage,
- deep sleep,
- cloudové odosielanie údajov,
- závislosť od internetu.

Odporúčaná stabilizácia senzora sa uvádza iba v dokumentácii:

- približne 60 sekúnd pri bežnom spustení,
- 5–10 minút po výraznej zmene prostredia,
- 10–15 minút pri kalibračnom porovnaní.

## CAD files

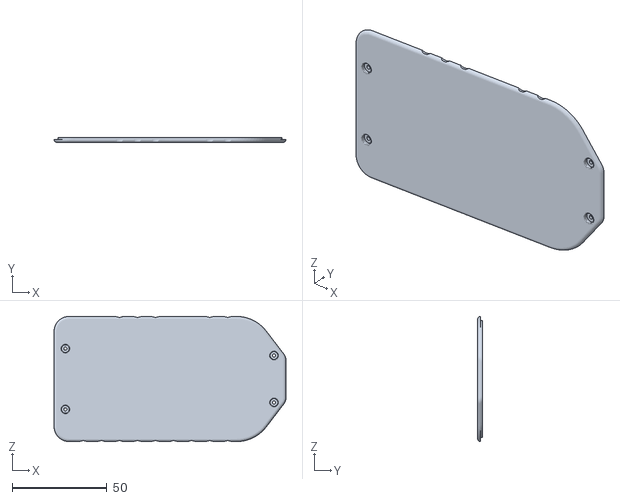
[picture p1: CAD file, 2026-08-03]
3D/Back.stl
122.2 x 2.50 x 66.0

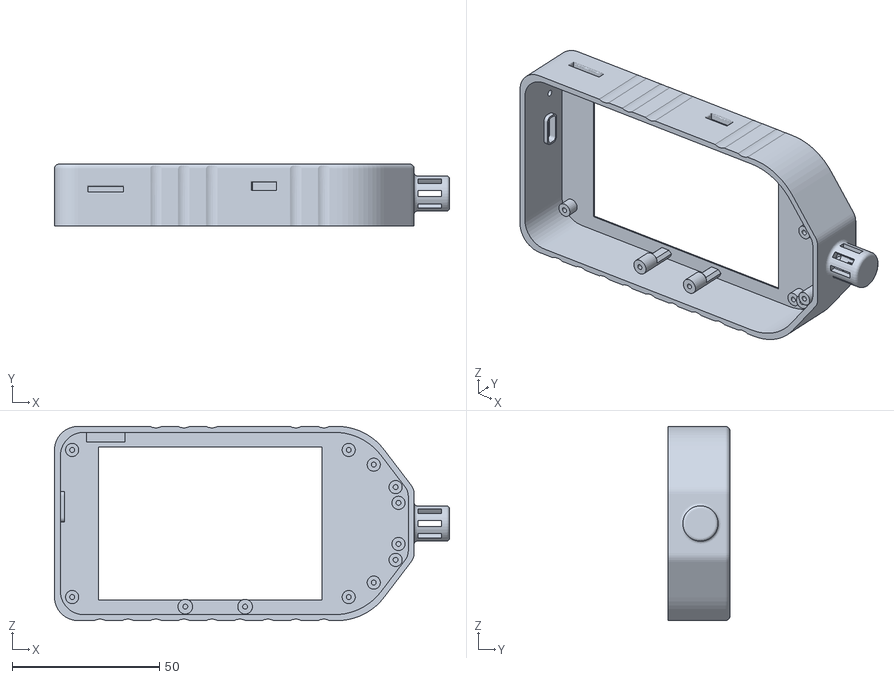
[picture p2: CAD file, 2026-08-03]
3D/Front.stl
134.3 x 21.0 x 66.0

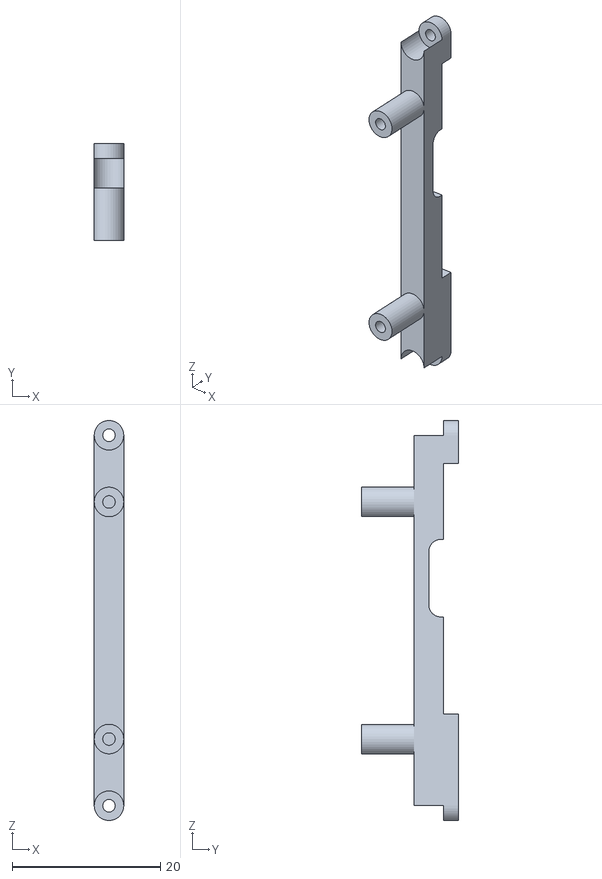
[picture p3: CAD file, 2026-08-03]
3D/Bridge.stl
4.00 x 13.1 x 54.0

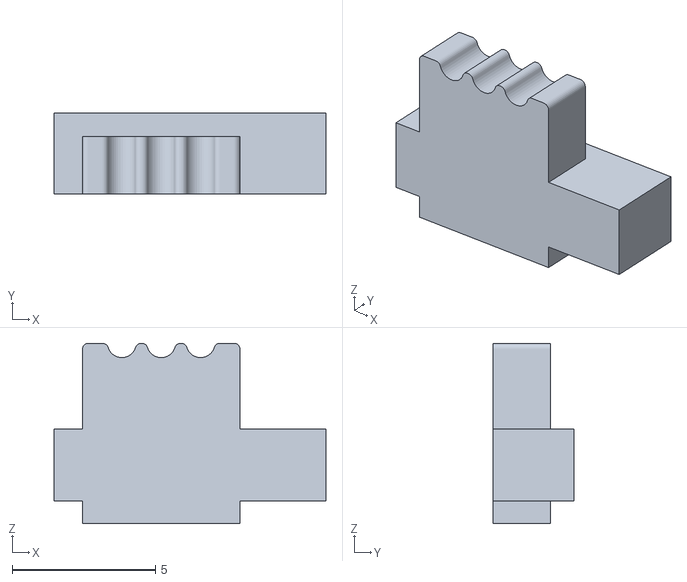
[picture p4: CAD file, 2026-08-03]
3D/Switch.stl
9.50 x 2.82 x 6.30

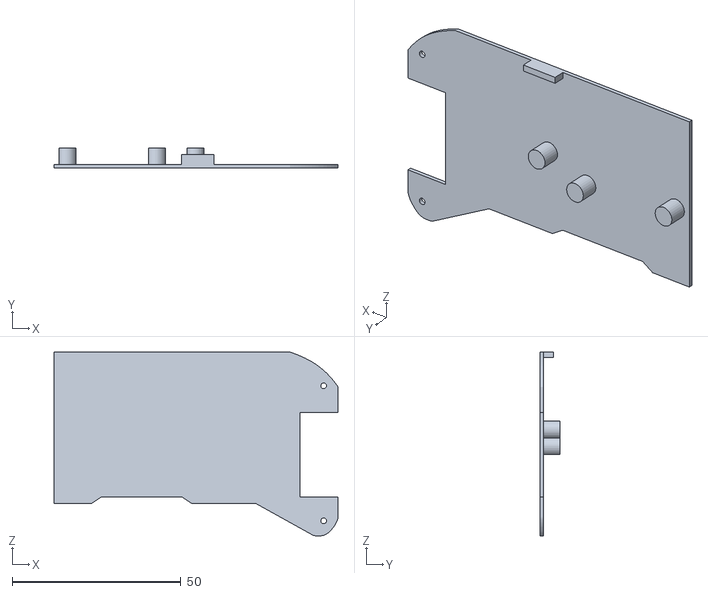
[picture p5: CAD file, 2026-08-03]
3D/Battery_bed.stl
84.3 x 5.80 x 54.6

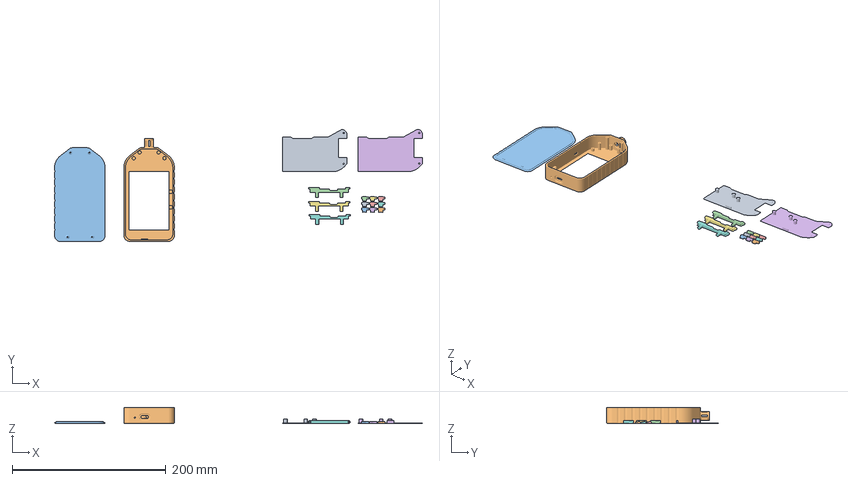
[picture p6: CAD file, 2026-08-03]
3D/Datalogger Enclosure Case.3mf
479.5 x 146.1 x 21.0 mm
Battery_bed x 2
Front
Back
Bridge x 3
Switch x 9

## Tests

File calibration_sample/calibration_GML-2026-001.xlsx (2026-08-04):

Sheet: calibration_GML_2026_001
etalon_temperature | etalon_pressure | etalon_humidity | logger_temperature | logger_pressure | logger_humidity | calibration_delta_temperature | calibration_delta_pressure | calibration_delta_humidity | model_temperature | model_pressure | model_humidity | delta_model_temperature | delta_model_pressure | delta_model_humidity
35.93 | 996.65 | 29.54 | 35.95 | 998.41 | 38.75 | -0.02 | -1.76 | -9.21 | 35.61 | 996.66 | 30.77 | 0.32 | -0.01 | -1.23
35.96 | 996.68 | 29.65 | 36.02 | 998.45 | 38.71 | -0.06 | -1.77 | -9.06 | 35.69 | 996.70 | 30.73 | 0.27 | -0.02 | -1.08
36.00 | 996.66 | 29.68 | 36.12 | 998.45 | 38.56 | -0.12 | -1.79 | -8.88 | 35.81 | 996.70 | 30.58 | 0.19 | -0.04 | -0.90
36.05 | 996.71 | 29.63 | 36.20 | 998.49 | 38.36 | -0.15 | -1.78 | -8.73 | 35.91 | 996.74 | 30.38 | 0.14 | -0.03 | -0.75
36.09 | 996.69 | 29.60 | 36.22 | 998.47 | 38.28 | -0.13 | -1.78 | -8.68 | 35.93 | 996.72 | 30.30 | 0.16 | -0.03 | -0.70
36.15 | 996.72 | 29.39 | 36.27 | 998.50 | 38.18 | -0.12 | -1.78 | -8.79 | 35.99 | 996.75 | 30.20 | 0.16 | -0.03 | -0.81
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

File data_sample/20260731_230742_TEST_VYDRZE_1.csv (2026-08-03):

session_id | timestamp | record_type | station | target_point | temperature_c | humidity_pct | pressure_hpa | battery_voltage_v | battery_percent | temperature_raw_c | humidity_raw_pct | pressure_raw_hpa | calibration_enabled | temperature_scale | temperature_offset_c | humidity_scale | humidity_offset_pct | pressure_scale | pressure_offset_hpa
20260731_230742 | 2026-07-31T23:07:42 | SESSION_START | TEST_VYDRZE_1 |  | 32.89 | 47.03 | 998.72 | 4.08 | 88 | 32.888 | 47.033 | 998.719 | 0 | 1.000000 | 0.000 | 1.000000 | 0.000 | 1.000000 | 0.000
20260731_230742 | 2026-07-31T23:07:46 | AUTO | TEST_VYDRZE_1 |  | 32.86 | 46.72 | 998.72 | 4.08 | 88 | 32.856 | 46.720 | 998.722 | 0 | 1.000000 | 0.000 | 1.000000 | 0.000 | 1.000000 | 0.000
20260731_230742 | 2026-07-31T23:07:51 | AUTO | TEST_VYDRZE_1 |  | 32.81 | 47.81 | 998.73 | 4.08 | 88 | 32.805 | 47.809 | 998.728 | 0 | 1.000000 | 0.000 | 1.000000 | 0.000 | 1.000000 | 0.000
20260731_230742 | 2026-07-31T23:07:56 | AUTO | TEST_VYDRZE_1 |  | 32.79 | 47.70 | 998.73 | 4.08 | 88 | 32.792 | 47.698 | 998.727 | 0 | 1.000000 | 0.000 | 1.000000 | 0.000 | 1.000000 | 0.000
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

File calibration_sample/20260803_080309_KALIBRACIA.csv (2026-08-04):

session_id | timestamp | record_type | station | target_point | temperature_c | humidity_pct | pressure_hpa | battery_voltage_v | battery_percent | temperature_raw_c | humidity_raw_pct | pressure_raw_hpa | calibration_enabled | temperature_scale | temperature_offset_c | humidity_scale | humidity_offset_pct | pressure_scale | pressure_offset_hpa
20260803_080309 | 2026-08-03T08:03:10 | SESSION_START | KALIBRACIA |  | 35.93 | 38.76 | 998.41 | 4.06 | 86 | 35.927 | 38.764 | 998.411 | 0 | 1.000000 | 0.000 | 1.000000 | 0.000 | 1.000000 | 0.000
20260803_080309 | 2026-08-03T08:03:10 | AUTO | KALIBRACIA |  | 35.95 | 38.75 | 998.41 | 4.06 | 86 | 35.946 | 38.747 | 998.408 | 0 | 1.000000 | 0.000 | 1.000000 | 0.000 | 1.000000 | 0.000
20260803_080309 | 2026-08-03T08:04:09 | AUTO | KALIBRACIA |  | 36.02 | 38.71 | 998.45 | 4.05 | 85 | 36.023 | 38.715 | 998.450 | 0 | 1.000000 | 0.000 | 1.000000 | 0.000 | 1.000000 | 0.000
20260803_080309 | 2026-08-03T08:05:09 | AUTO | KALIBRACIA |  | 36.12 | 38.56 | 998.45 | 4.05 | 85 | 36.125 | 38.564 | 998.445 | 0 | 1.000000 | 0.000 | 1.000000 | 0.000 | 1.000000 | 0.000
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

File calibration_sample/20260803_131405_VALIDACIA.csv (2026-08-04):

session_id | timestamp | record_type | station | target_point | temperature_c | humidity_pct | pressure_hpa | battery_voltage_v | battery_percent | temperature_raw_c | humidity_raw_pct | pressure_raw_hpa | calibration_enabled | temperature_scale | temperature_offset_c | humidity_scale | humidity_offset_pct | pressure_scale | pressure_offset_hpa
20260803_131405 | 2026-08-03T13:14:05 | SESSION_START | VALIDACIA |  | 37.30 | 30.76 | 995.82 | 3.92 | 70 | 37.374 | 38.738 | 997.566 | 1 | 1.189254 | -7.147 | 1.000000 | -7.977 | 1.000000 | -1.747
20260803_131405 | 2026-08-03T13:14:05 | AUTO | VALIDACIA |  | 37.30 | 30.73 | 995.82 | 3.92 | 70 | 37.372 | 38.707 | 997.566 | 1 | 1.189254 | -7.147 | 1.000000 | -7.977 | 1.000000 | -1.747
20260803_131405 | 2026-08-03T13:15:05 | AUTO | VALIDACIA |  | 37.04 | 28.47 | 995.82 | 3.92 | 69 | 37.153 | 36.447 | 997.568 | 1 | 1.189254 | -7.147 | 1.000000 | -7.977 | 1.000000 | -1.747
20260803_131405 | 2026-08-03T13:16:05 | AUTO | VALIDACIA |  | 36.96 | 28.64 | 995.80 | 3.92 | 69 | 37.089 | 36.613 | 997.545 | 1 | 1.189254 | -7.147 | 1.000000 | -7.977 | 1.000000 | -1.747
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

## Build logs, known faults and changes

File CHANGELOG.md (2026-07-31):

# Changelog – GeoMeteo Logger

Všetky významné zmeny firmvéru GeoMeteo Logger sú uvedené v tomto dokumente.

Formát verzie:

```text
MAJOR.MINOR.PATCH
```

Zmena používateľských nastavení, najmä kalibračných koeficientov, jasu, intervalu záznamu alebo farebnej schémy, nemení číslo verzie firmvéru.

---

## Stav vydaní

| Verzia | Stav |
|---|---|
| v0.9.0 | kandidát na overenie – ochrana úložiska |
| v0.8.2 | vývojová verzia – rozšírené farebné schémy |
| v0.7.6 | označená ako stabilný referenčný release |
| v0.7.5 | experimentálna, následne zrušená |
| v0.2.0–v0.7.4 | historické vývojové míľniky |

---

## v0.9.0 – ochrana úložiska

### Pridané

- kontrola celkovej, využitej a voľnej kapacity SD karty,
- pravidelná obnova informácie o voľnom priestore,
- upozornenie pri menej ako 32 MiB voľného miesta,
- zastavenie bežných zápisov pri zostávajúcej rezerve približne 4 MiB,
- núdzová rezerva 64 KiB na korektné ukončenie relácie,
- preventívne delenie CSV pred limitom FAT32 pri približne 3800 MiB,
- pokračovacie súbory `_part02`, `_part03` a ďalšie,
- systémové udalosti `FILE_CONTINUE` a `FILE_RESUME`,
- uloženie čísla aktuálnej časti do stavu obnovy,
- podpora najviac 32 častí jednej relácie,
- testovací režim rotácie pri približne 64 KiB,
- spracovanie viacdielnych relácií v grafoch,
- spracovanie viacdielnych relácií v archíve,
- zobrazenie počtu častí a celkovej veľkosti relácie,
- samostatné sťahovanie častí cez Wi‑Fi export.

### Poznámka

Produkčné nastavenie musí používať:

```cpp
constexpr bool STORAGE_ROTATION_TEST_MODE = false;
```

---

## v0.8.2 – konzistentné stavové farby

### Zmenené

- stavové indikátory `SENZOR`, `SD`, `RELACIA` a `ZAZNAM` prestali podliehať farebnej téme,
- zavedená pevná zelená farba pre stav OK,
- zavedená pevná oranžová farba pre upozornenie alebo neaktívny stav,
- zavedená pevná červená farba pre chybu,
- ostatné prvky používateľského rozhrania naďalej používajú zvolenú tému.

---

## v0.8.1 – rozšírené farebné schémy

### Pridané

K pôvodným témam pribudli:

- sivá,
- žltá,
- limetková zelená,
- krémová,
- ružová.

### Zmenené

- výber tém bol upravený na rozloženie dva stĺpce × päť riadkov,
- menší font názvov tém zlepšil čitateľnosť v kompaktnejšom menu.

---

## v0.8.0 – voľba akcentovej farby

### Pridané

- samostatné menu farebnej schémy,
- oranžová téma,
- modrá téma,
- zelená téma,
- červená téma,
- fialová téma,
- okamžitý náhľad vybranej farby,
- uloženie témy do `Preferences`,
- aplikovanie témy na Wi‑Fi webovú stránku.

### Zmenené

Farebná téma začala ovplyvňovať:

- panely meraných hodnôt,
- tlačidlá,
- ikony,
- aktívne položky,
- rámčeky,
- posuvník jasu,
- grafické akcenty.

---

## v0.7.6 – stabilný referenčný release

### Stav

Táto verzia bola používateľom označená ako stable release.

### Zmenené

- návrat k čistému GUI založenému na v0.7.4,
- odstránenie experimentálne dokresľovanej diakritiky,
- odstránenie bieleho obrysu meraných hodnôt,
- zachovaný iba jemný bold efekt meraných hodnôt,
- verzia označená ako v0.7.6.

### Zachované

- relácie,
- automatické a manuálne záznamy,
- grafy,
- archív,
- kalibrácia,
- úspora energie,
- Wi‑Fi export,
- stabilizované GUI.

---

## v0.7.5 – experiment čitateľnosti a diakritiky

### Pridané

- biely obrys okolo meraných hodnôt,
- graficky dokresľované dĺžne a mäkčene na hlavných tlačidlách.

### Problémy

- prvá verzia neprešla kompiláciou pre umiestnenie typov používaných automatickými Arduino prototypmi,
- po oprave pôsobil biely obrys aj dokresľovaná diakritika príliš rušivo.

### Stav

Verzia bola zrušená a nebola použitá ako základ stabilného releasu.

---

## v0.7.4 – jedno tlačidlo relácie

### Zmenené

- samostatné tlačidlá založenia a ukončenia relácie boli spojené,
- bez aktívnej relácie tlačidlo reláciu spustí,
- počas aktívnej relácie rovnaké tlačidlo otvorí potvrdenie ukončenia,
- tlačidlo využíva celú šírku hlavnej obrazovky.

---

## v0.7.3 – prvá väčšia úprava GUI

### Zmenené

- počet manuálnych záznamov sa zobrazuje ako `MANUAL:`,
- stavový riadok používa menší alebo viacriadkový text podľa dĺžky správy,
- zväčšené skratky a dotykové plochy podmenu,
- v kalibrácii bol názov `SUROVA` zmenený na `MERANA`,
- kalibrácia používa jedno tlačidlo zapnutia alebo vypnutia,
- tlačidlo úspory bolo premenované na `USPORA ENERGIE`,
- kalibračný editor bol vizuálne zjednotený s ostatnými vstupmi,
- stavové indikátory používajú celé názvy,
- panely meraných veličín dostali farebné pozadie,
- vykresľovanie viacerých obrazoviek bolo zmenené na čiastočné.

### Opravené

- znížené blikanie hlavnej obrazovky,
- znížené blikanie kalibračného menu,
- znížené blikanie Wi‑Fi menu,
- menej časté prekresľovanie súhrnu grafov.

---

## v0.7.2 – opravy Wi‑Fi exportu

### Pridané

- dodaná bitmapová Wi‑Fi ikona 32 × 32 px.

### Opravené

- Wi‑Fi sa už nevypne pri kliknutí na stiahnutie CSV,
- čas nečinnosti sa obnoví po dokončení prenosu,
- odstránené podtečenie časovača spôsobené starou hodnotou `millis()`,
- Wi‑Fi ikona sa už nevykresľuje cez obrazovku exportu,
- ikona sa zobrazuje iba v spodnej lište hlavnej obrazovky.

---

## v0.7.1 – oprava kompilácie Wi‑Fi verzie

### Opravené

- pridaná explicitná dopredná deklarácia funkcie `formatArchiveDateTime()`,
- odstránená chyba:

```text
'formatArchiveDateTime' was not declared in this scope
```

---

## v0.7.0 – Wi‑Fi export CSV

### Pridané

- režim Wi‑Fi SoftAP,
- vlastná sieť `GeoMeteo-XXXX`,
- heslo `geometeo`,
- lokálna adresa `192.168.4.1`,
- webový server na porte 80,
- zoznam ukončených relácií v prehliadači,
- stiahnutie CSV zo SD karty,
- automatické vypnutie Wi‑Fi po piatich minútach nečinnosti,
- najviac štyria klienti,
- blokovanie exportu počas aktívnej relácie,
- dočasné vypnutie úspory displeja počas exportu.

---

## v0.6.0 – úspora energie

### Pridané

- samostatné menu úspory energie,
- voľba stlmenia po 30 sekundách, 1 minúte, 2 minútach alebo 5 minútach,
- stlmenie displeja na približne 5 %,
- úplné vypnutie podsvietenia po ďalších 30 sekundách,
- prvý dotyk iba prebúdza displej,
- uloženie nastavenia do `Preferences`.

### Zachované počas vypnutia displeja

- meranie senzorov,
- RTC,
- automatický zápis,
- kontrola batérie,
- kontrola SD,
- relácia a štatistiky.

---

## v0.5.0 – kalibrácia

### Pridané

- lineárna korekcia `y = a × x + b`,
- samostatná kalibrácia teploty,
- samostatná kalibrácia vlhkosti,
- samostatná kalibrácia tlaku,
- editor koeficientov,
- živé zobrazenie meranej a korigovanej hodnoty,
- uloženie koeficientov do `Preferences`,
- zapnutie a vypnutie kalibrácie,
- blokovanie zmeny počas aktívnej relácie,
- validácia povolených rozsahov koeficientov.

### Zmenené

CSV bolo rozšírené o:

- surovú teplotu,
- surovú vlhkosť,
- surový tlak,
- stav kalibrácie,
- všetky mierkové a offsetové koeficienty.

Grafy a štatistiky používajú korigované hodnoty.

---

## v0.4.0 – archív relácií

### Pridané

- skratka archívu na hlavnej obrazovke,
- zoznam ukončených relácií,
- zoradenie od najnovšej,
- stránkovanie po piatich položkách,
- manuálne obnovenie zoznamu,
- kapacita najviac 96 relácií,
- detail relácie,
- počet automatických a manuálnych záznamov,
- trvanie relácie,
- minimum, priemer a maximum veličín,
- grafy archivovaných relácií.

### Filtrovanie

Do archívu sa zaraďujú relácie ukončené udalosťou:

- `SESSION_END`
- `SESSION_END_RECOVERY`
- `SESSION_ABANDONED`

---

## v0.3.1 – živé grafy

### Pridané

- priebežná aktualizácia grafu počas aktívnej relácie,
- režim `120` sa aktualizuje po každom úspešnom `AUTO` zázname,
- režim `VSETKY` sa pri menších reláciách aktualizuje priamo,
- veľká relácia sa znovu načíta najviac raz za 10 sekúnd,
- súhrn a trvanie sa obnovujú nezávisle.

---

## v0.3.0 – grafy a súhrn relácie

### Pridané

- bitmapová ikona grafov,
- skratka do grafického menu,
- graf teploty,
- graf vlhkosti,
- graf tlaku,
- rozsah posledných 120 automatických záznamov,
- rozsah všetkých záznamov,
- agregácia celej relácie do najviac 240 bodov,
- minimum, priemer a maximum,
- časový rozsah grafu,
- súhrn stanoviska a počtu záznamov.

---

## v0.2.0 – stabilizovaný prototyp

### Pridané

- centrálne označenie názvu a verzie firmvéru,
- obnova nedokončenej relácie po reštarte,
- uloženie aktívneho stavu do `Preferences`,
- možnosti pokračovať, ukončiť alebo opustiť reláciu,
- opakovaný pokus o inicializáciu a zápis na SD kartu,
- maximálne dva pokusy o zápis,
- validácia teploty, vlhkosti, tlaku a RTC,
- upozornenie na nízky a kritický stav batérie,
- bezpečné zvýšenie manuálneho počítadla až po úspešnom zápise.

### Základná funkcionalita zahrnutá v tomto míľniku

- externý SHT40 a BMP280,
- RTC DS3231,
- SD karta,
- dotykové GUI,
- automatický záznam,
- manuálny záznam,
- stanovisko a meraný bod,
- samostatný CSV súbor pre reláciu,
- `SESSION_START` a `SESSION_END`.

---

## Pred v0.2.0 – nečíslovaný prototyp

Prvé funkčné prototypy overili:

- oddelenie internej a externej I²C zbernice,
- komunikáciu so SHT40,
- komunikáciu s BMP280,
- komunikáciu s DS3231,
- inicializáciu SD karty,
- čítanie napätia batérie,
- portrétnu orientáciu displeja,
- správnu transformáciu dotykových súradníc,
- základnú hlavnú obrazovku,
- prvé CSV záznamy,
- zadávanie stanoviska a meraného bodu.

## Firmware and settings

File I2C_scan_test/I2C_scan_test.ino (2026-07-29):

/* 
 * I2C test for LaskaKit ESPD-3.5" 320x480, ILI9488 https://www.laskakit.cz/laskakit-espd-35-esp32-3-5-tft-ili9488-touch/
 * example from TFT_eSPI library is used
 * 
 * How to steps:
 * 1. Copy file from https://github.com/LaskaKit/ESPD-35/tree/main/SW to Arduino/libraries/TFT_eSPI/User_Setups/
 *    - for version v2.3 and before:  Setup300_ILI9488_ESPD-3_5_v2.h 
 *    - for version v3 and above:     Setup303_ILI9488_ESPD-3_5_v3.h
 * 2. in Arduino/libraries/TFT_eSPI/User_Setup_Select.h 
      a. comment: #include <User_Setup.h> 
      b. add: 
          - for version v2.3 and before:  #include <User_Setups/Setup300_ILI9488_ESPD-3_5_v2.h>  // Setup file for LaskaKit ESPD-3.5" 320x480, ILI9488 
          - for version v3 and above:     #include <User_Setups/Setup303_ILI9488_ESPD-3_5_v3.h>  // Setup file for LaskaKit ESPD-3.5" 320x480, ILI9488 V3
 * 
 * Board constants:
      TFT_BL          - LED back-light use: analogWrite(TFT_BL, TFT_BL_PWM);
      POWER_OFF_PIN   - Pull LOW to switch board off
      TOUCH_INT       - Touch interrupt pin
    * I2C (µŠup and devices (only from v3)):
      I2C_SDA         - Data pin 
      I2C_SCL         - Clock pin
    * SPI (µŠup (only from v3) and SD card):
      SPI_MISO        - MISO pin
      SPI_MOSI        - MOSI pin
      SPI_SCK         - Clock pin
      SPI_USUP_CS     - µŠup Chip Select pin (only from v3)
      SPI_SD_CS       - SD Card Chip Select pin
    * I2S (only from v3):
      I2S_LRC         - Word select a.k.a. left-right clock pin
      I2S_DOUT        - Serial data pin
      I2S_BCLK        - Serial clock a.k.a. bit clock pin
    * Battery mesurement:
      BAT_PIN         - Battery voltage mesurement
      deviderRatio    - Voltage devider ratio on ADC pin 1MOhm + 1.3MOhm
 *
 * Email:podpora@laskakit.cz
 * Web:laskakit.cz
*/


#include <Arduino.h>
#include "Wire.h"
#include <TFT_eSPI.h> // Hardware-specific library
#include <SPI.h>

// TFT SPI
#define TFT_BL_PWM 255 // Backlight brightness 0-255
#define TFT_DISPLAY_RESOLUTION_X 480
#define TFT_DISPLAY_RESOLUTION_Y 320
#define TEXT_PADDING 30

TFT_eSPI tft = TFT_eSPI(); // Invoke custom library with default width and height

void displayInit() {
  tft.init();
  tft.setRotation(1);
  tft.fillScreen(TFT_BLACK);
}

void setup() {
  Serial.begin(115200);
  Wire.begin(I2C_SDA, I2C_SCL);
  displayInit();
  analogWrite(TFT_BL, TFT_BL_PWM);      // Set brightness of backlight
}

void loop() {
  byte error, address;
  int nDevices = 0;

  tft.fillScreen(TFT_BLACK);
  tft.setTextSize(1);
  tft.setTextFont(4);
  tft.setTextColor(TFT_WHITE, TFT_BLACK);
  tft.setTextDatum(BC_DATUM);
  tft.drawString("Scanning for I2C devices...", TFT_DISPLAY_RESOLUTION_X / 2, TEXT_PADDING);
  for (address = 0x01; address < 0x7f; address++)
  {
    Wire.beginTransmission(address);
    error = Wire.endTransmission();
    if (error == 0)
    {
      nDevices++;
      tft.drawString("I2C device found at address 0x" + String(address), TFT_DISPLAY_RESOLUTION_X / 2, TEXT_PADDING * nDevices + TEXT_PADDING);
    }
    else if (error != 2)
    {
      if (nDevices)
      {
        tft.drawString("Error" + String(error) + "at address 0x" + String(address), TFT_DISPLAY_RESOLUTION_X / 2, TEXT_PADDING * nDevices + 2 * TEXT_PADDING);
      }
      else
      {
        tft.drawString("Error" + String(error) + "at address 0x" + String(address), TFT_DISPLAY_RESOLUTION_X / 2, TEXT_PADDING * 2);
      }
    }
  }
  if (nDevices == 0)
  {
    tft.drawString("No I2C devices found", TFT_DISPLAY_RESOLUTION_X / 2, TEXT_PADDING * 2);
    tft.drawString("Next scanning in 5 seconds...", TFT_DISPLAY_RESOLUTION_X / 2, TEXT_PADDING * 3);
  }
  else
  {
    tft.drawString("Next scanning in 5 seconds...", TFT_DISPLAY_RESOLUTION_X / 2, TEXT_PADDING * nDevices + 2 * TEXT_PADDING);
  }
  delay(5000);
}

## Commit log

2026-08-03 3D files and new versions
    [20260731_230742_TEST_VYDRZE_1.csv, Back.stl, Battery_bed.stl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]
2026-08-04 calibration and 3D files
    [20260803_080309_KALIBRACIA.csv, 20260803_131405_VALIDACIA.csv, calibration_GML-2026-001.xlsx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]
